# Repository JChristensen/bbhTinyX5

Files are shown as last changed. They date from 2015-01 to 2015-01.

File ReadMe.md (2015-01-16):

# ATtinyX5 Breadboard Helper #
http://github.com/JChristensen/bbhTinyX5  
ReadMe file  
Jack Christensen Jan 2015  

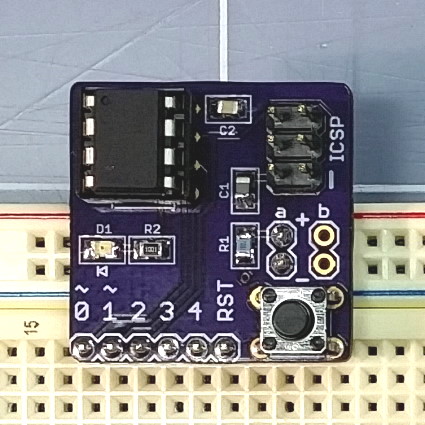
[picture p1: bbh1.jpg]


## Introduction ##

ATtiny Breadboard Helpers are the easiest way to breadboard Atmel ATtiny24/44/84 and ATtiny25/45/85 micrcontrollers! These small boards contain everything needed to run an ATtiny microcontroller, including:
- ICSP header
- Filter and bypass capacitors
- Reset button with pullup resistor
- LED with current-limiting resistor

The Breadboard Helper breaks out all the MCU's pins to a header and also connects to the breadboard's power rails. Plug the Breadboard Helper into a breadboard, add power, connect a programmer, and the microcontroller is ready to go!

PC boards can be ordered [from OSH Park](https://oshpark.com/shared_projects/kbM0Jfiz).  
A Bill of Materials with Mouser part numbers is part of this repo.  
See the ATtinyX4 Breadboard Helper [here](https://github.com/JChristensen/bbhTinyX4).

## Power Connection (see photos below)##

A two-pin header connects the Breadboard Helper to the breadboard's power rails. This header should be soldered ***either*** into the position labeled **"a"** ***or*** into the position labeled **"b"**.

Use position **"a"** for breadboards where the power rail holes line up with those in the main part of the breadboard (most full-size breadboards). Use position **"b"** for breadboards where the power rail holes are staggered between those in the main part of the breadboard (most half-size breadboards).

Observe polarity carefully and ***do not*** solder headers into both positions **"a"** and **"b"**, as the result will likely not fit into any breadboard!

## Arduino Pin Mapping ##

The 6-pin header is labeled with Arduino pin numbers 0-4 plus RESET, using the pin mapping from the [Arduino-Tiny core](https://code.google.com/p/arduino-tiny/). Other cores may be used with the Breadboard Helper but be aware that the pin mapping may be different. The AVR port and pin numbers are also labeled for easy reference.

The LED is connected to Arduino pin 2 or PB2 (SCK/USCK/SCL/ADC1/T0/INT0/PCINT2).

## Make the right power connection ##

Some breadboards have holes in the power rails that line up with those in the main part of the breadboard -- this is **Type "a"**.  

Some breadboards have holes in the power rails that are staggered between those in the main part of the breadboard -- this is **Type "b"**.  





Solder the two-pin power rail header into position **"a"** *or* position **"b"**, *NOT BOTH!*



Add power (observe polarity!), connect a programmer and the ATtiny is ready to go!



## CC BY-SA ##
"ATtinyX5 Breadboard Helper" by Jack Christensen is licensed under [CC BY-SA 4.0](http://creativecommons.org/licenses/by-sa/4.0/).

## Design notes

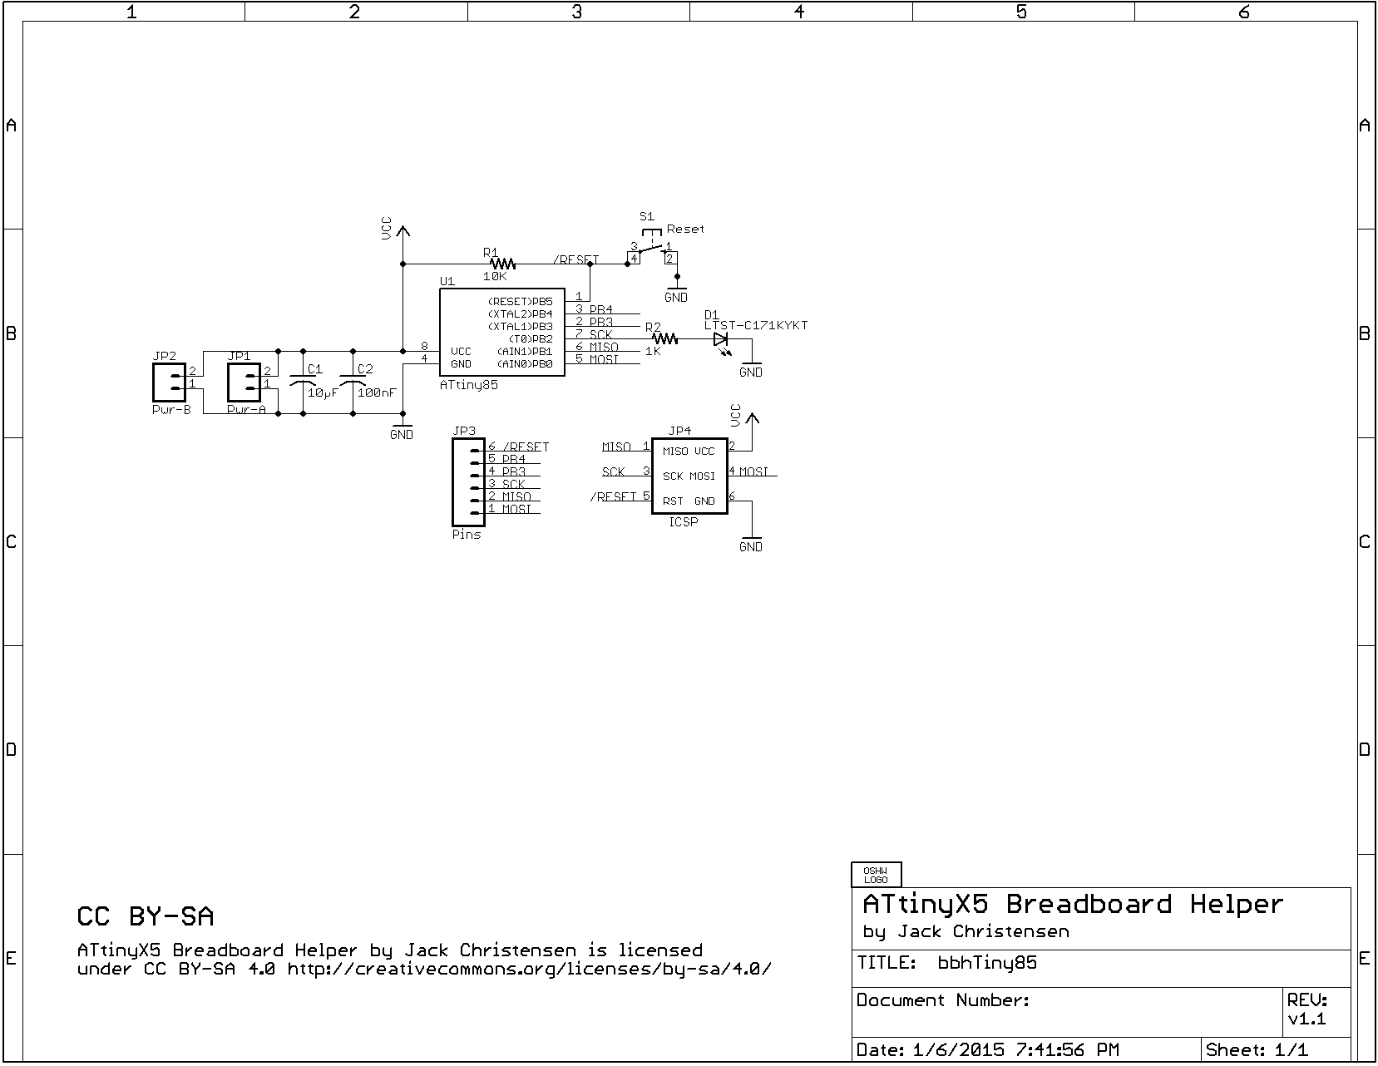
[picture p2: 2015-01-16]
schematic.png

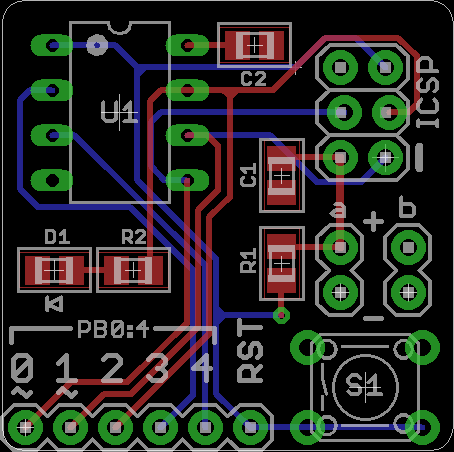
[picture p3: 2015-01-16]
board.png

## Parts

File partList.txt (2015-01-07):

Partlist

Exported from bbhTiny85.sch at 12/17/2014 6:19:00 PM

EAGLE Version 6.4.0 Copyright (c) 1988-2013 CadSoft

Assembly variant: 

Part     Value          Device                Package     Library  Sheet

C1       10µF           C-USM0805             M0805       _jc      1
C2       100nF          C-USM0805             M0805       _jc      1
D1       Yellow         LEDD0805A             D0805A      _jc      1
JP1      Pwr-A          M02PTH                1X02        SparkFun 1
JP2      Pwr-B          M02PTH                1X02        SparkFun 1
JP3      Pins           M06SIP                1X06        SparkFun 1
JP4      ICSP           AVR_SPI_PRG_62X3_LOCK 2X3_LOCK    _jc      1
R1       10K            R-US_M0805            M0805       _jc      1
R2       1K             R-US_M0805            M0805       _jc      1
S1       Reset          10-XXOCT              B3F-10XXOCT _jc      1
U1       ATtiny85       TINY10P               DIL08       atmel    1

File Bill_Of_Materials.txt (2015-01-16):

ATtinyX5 Breadboard Helper
Bill of Materials
Jack Christensen Jan 2015 

Part     Value      Manufacturer     Manufacturer Part No.    Mouser Part No.
C1       10µF       Murata           GRM21BR71A106KA73L       81-GRM21BR71A106KA3L
C2       100nF      AVX              08055C104KAT2A           581-08055C104K
D1       Yellow     Lite-On          LTST-C171YKT             859-LTST-C171YKT
R1       10K        KOA Speer        RK73H2ATTD1002F          660-RK73H2ATTD1002F
R2       1K         KOA Speer        RK73H2ATTD1001F          660-RK73H2ATTD1001F
S1       Reset      Omron            B3F-1020                 653-B3F-1020
U1       ATtinyX5   Atmel            ATtiny85V-10PU           556-ATTINY85V10PU

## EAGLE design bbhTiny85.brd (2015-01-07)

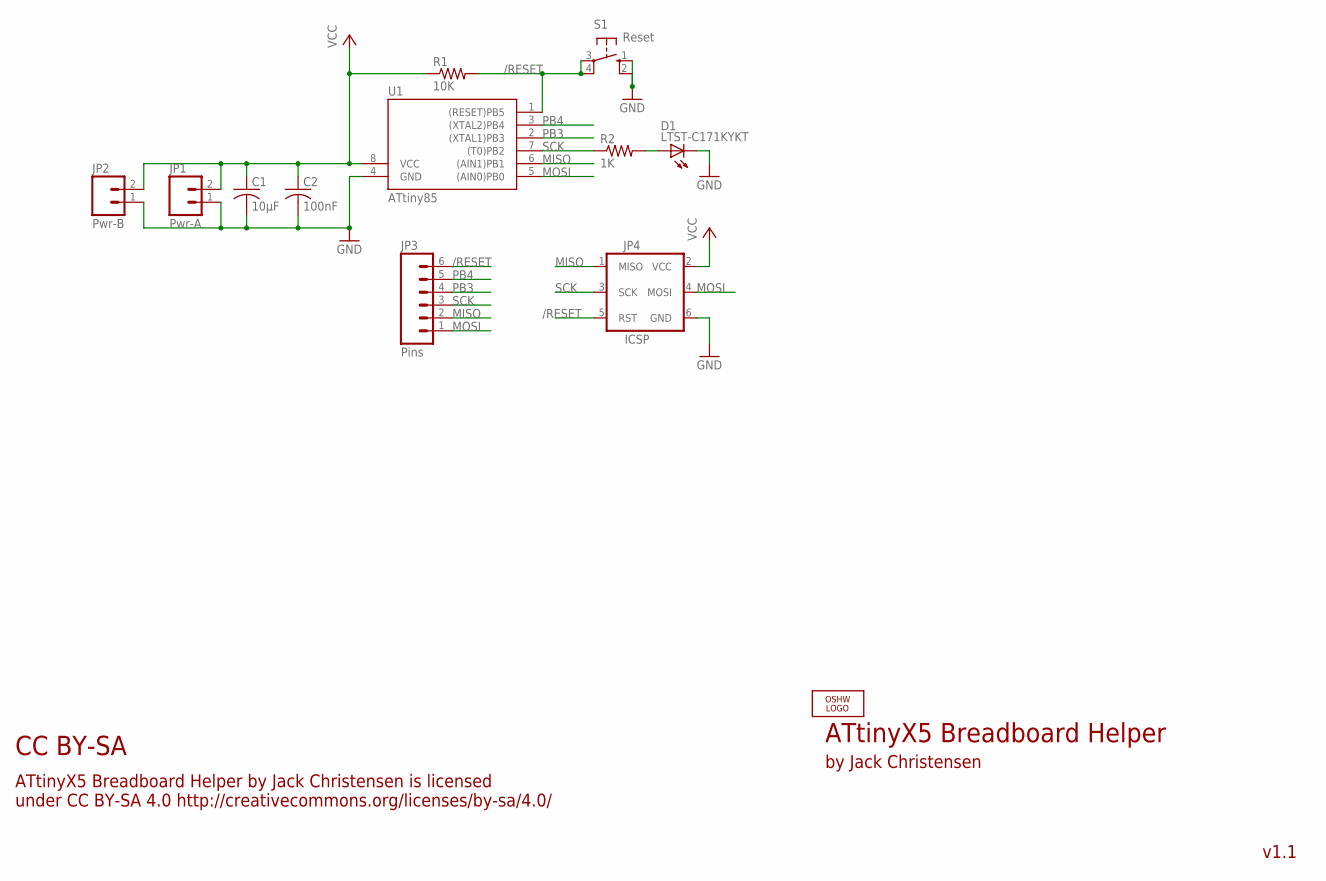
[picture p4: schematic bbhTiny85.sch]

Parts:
C1: 10µF; M0805
C2: 100nF; M0805
D1: LTST-C171KYKT; D0805A
JP1: Pwr-A; 1X02
JP2: Pwr-B; 1X02
JP3: Pins; 1X06
JP4: ICSP; 2X3_LOCK
LOGO1: OSHW_LOGO_8MILX0100-NT; OSHW_8X100_NOTEXT
R1: 10K; M0805
R2: 1K; M0805
S1: Reset; B3F-10XXOCT
U1: ATtiny85; DIL08

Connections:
/RESET: JP3.6, JP4.5 (RST), R1.2, S1.3, S1.4 (P1), U1.1 ((RESET)PB5)
GND: C1.2, C2.2, D1.K (C), JP1.1, JP2.1, JP4.6 (GND), S1.1 (S), S1.2 (S1), U1.4 (GND)
MISO: JP3.2, JP4.1 (MISO), U1.6 ((AIN1)PB1)
MOSI: JP3.1, JP4.4 (MOSI), U1.5 ((AIN0)PB0)
unnamed: D1.A, R2.2
PB3: JP3.4, U1.2 ((XTAL1)PB3)
PB4: JP3.5, U1.3 ((XTAL2)PB4)
SCK: JP3.3, JP4.3 (SCK), R2.1, U1.7 ((T0)PB2)
VCC: C1.1, C2.1, JP1.2, JP2.2, JP4.2 (VCC), R1.1, U1.8 (VCC)

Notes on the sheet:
ATtinyX5 Breadboard Helper
by Jack Christensen
ATtinyX5 Breadboard Helper by Jack Christensen is licensed under CC BY-SA 4.0 http://creativecommons.org/licenses/by-sa/4.0/
CC BY-SA
v1.1

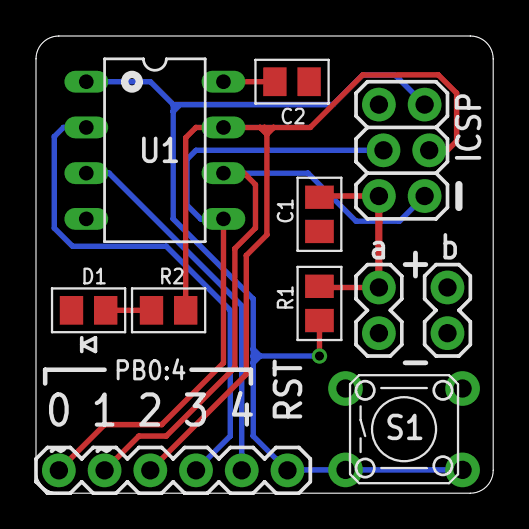
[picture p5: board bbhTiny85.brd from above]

Board: 2 copper layers, 25.4 x 25.4 mm, 12 parts (1 on the bottom side), 9 nets.

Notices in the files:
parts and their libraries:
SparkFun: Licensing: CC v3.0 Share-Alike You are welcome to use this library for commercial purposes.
